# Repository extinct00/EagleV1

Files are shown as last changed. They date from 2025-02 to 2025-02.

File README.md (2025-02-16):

# EagleV1

## Low-cost split column-staggered ergonomic keyboard
A Corne-like split keyboard with a little bit wider thumb-cluster and more agressive pinky stagger. This keyboard is designed to be compatible with RedDragon LowProfile switches that are widely avaialable on AliExpress for very cheap. They have the same height as
Khail LP switches (around 12mm) and can be used with classic MX style keycaps, although some might hit the upper housing. Preffered are any keycaps compatible with Numphy keyboards or any 3D printed, either FDM or SLA.

---

## Table of Contents
1. [Introduction](#introduction)
2. [Features](#features)
3. [Bill of Materials](#bill-of-materials)
4. [Build Instructions](#build-instructions)
5. [Pictures](#pictures)
6. [Contributing](#contributing)
7. [License](#license)

---

## Introduction
This project is designed to create a split ergonomic keyboard that is both low-cost and low-profile. The keyboard is split into two halves, allowing for a more natural hand position and reducing strain during long typing sessions. The low-profile design ensures a sleek and modern look while maintaining comfort.

---

## Features
- **Split Design**: Ergonomically designed to reduce strain on your hands and wrists.
- **Low-Cost**: Built with affordable components to keep the project accessible.
- **Low-Profile**: Sleek and compact design for a modern look.
- **Customizable**: Open-source firmware and hardware for easy customization.

---

## Bill of Materials
Here’s a list of components you’ll need to build this keyboard. (You can fill this section with the specific parts you used.)

1. **Microcontroller**: (e.g., Pro Micro, RP2040, etc.)
2. **Key Switches**: (e.g., Low-profile mechanical switches)
3. **Keycaps**: (e.g., Low-profile keycaps)
4. **PCB or Handwiring Materials**: (e.g., PCB, diodes, wires)
5. **Case**: (e.g., 3D-printed or acrylic case)
6. **Connectors**: (e.g., TRRS cable for split communication)
7. **Miscellaneous**: (e.g., screws, standoffs, etc.)

---

## Build Instructions
Below is a step-by-step guide to building your split ergonomic keyboard. (You can fill in the details as you progress.)

### Step 1: Gather All Components
Ensure you have all the components listed in the [Bill of Materials](#bill-of-materials) section.

### Step 2: Prepare the PCB or Handwiring
- If using a PCB, solder the diodes and microcontroller.
- If handwiring, follow the wiring diagram and connect the switches to the microcontroller.

### Step 3: Assemble the Case
- Attach the switches to the case.
- Secure the PCB or handwired assembly into the case.

### Step 4: Connect the Two Halves
- Use a TRRS cable to connect the two halves of the keyboard.
- Ensure the firmware supports split communication.

### Step 5: Flash the Firmware
- Download and flash the firmware to the microcontroller.
- Customize the keymap if needed.

### Step 6: Test the Keyboard
- Connect the keyboard to your computer and test all keys.
- Make adjustments as necessary.

---

## Pictures
Here are some pictures of my progress and the final build. (You can add images from the `Pictures` folder as you go.)

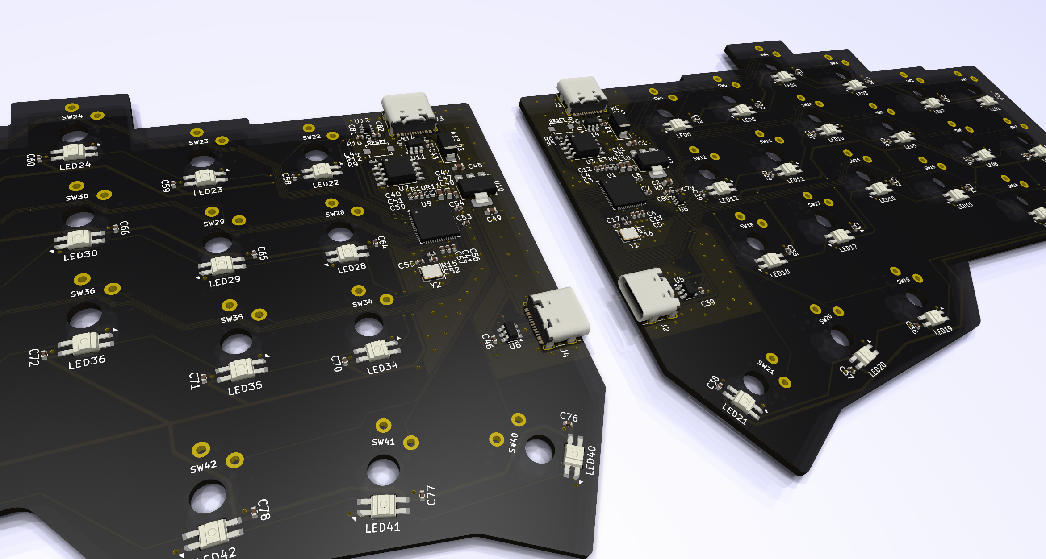
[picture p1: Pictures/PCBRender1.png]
Progress Photo 1

Progress Photo 2
Final Build

---

## Contributing
Contributions are welcome! If you have any suggestions, improvements, or bug fixes, feel free to open an issue or submit a pull request.

---

## License
This project is licensed under the [MIT License](LICENSE). Feel free to use, modify, and distribute it as you see fit.

---

Happy building! 🎛️

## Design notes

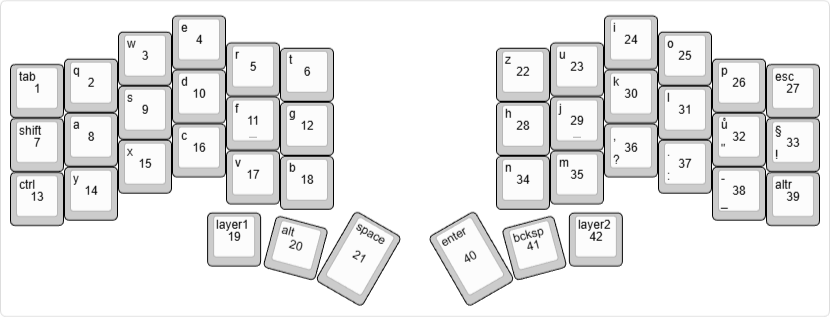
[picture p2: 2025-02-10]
Plate v3/project-eagle.png

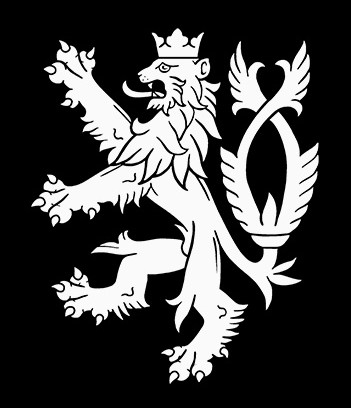
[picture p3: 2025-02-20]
PCB/EagleV1/_vyrn_1939plachta-lev.jpg

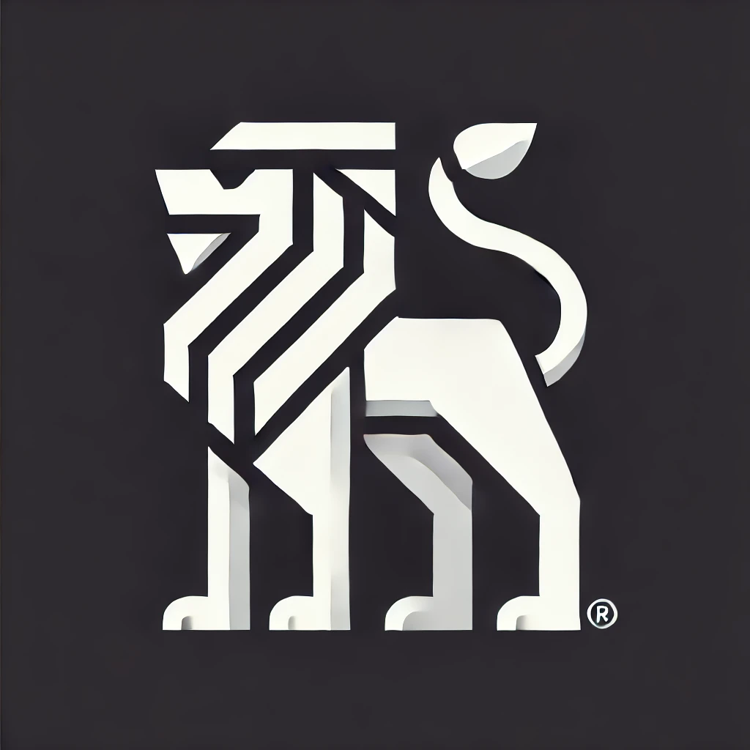
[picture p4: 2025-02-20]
PCB/EagleV1/cesky_lev_gpt.webp

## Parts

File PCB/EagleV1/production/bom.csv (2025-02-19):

Designator | Footprint | Quantity | Value | LCSC Part #
C1, C11, C2, C42, C45, C47, C49, C9 | 0603 | 8 | 1u
C10, C12, C13, C14, C15, C18, C19, C20, C21, C22, C23, C24, C25, C26, C27, C28, C29, C3, C30, C31, C32, C33, C34, C35, C36, C37, C38, C39, C4, C40, C41, C43, C44, C46, C48, C5, C50, C51, C53, C54, C56, C57, C58, C59, C6, C60, C61, C62, C63, C64, C65, C66, C67, C68, C69, C7, C70, C71, C72, C73, C74, C75, C76, C77, C78, C79, C8, C80, C81, C82 | 0402 | 70 | 100n
C16, C17, C52, C55 | 0402 | 4 | 15p
D1, D2 | D_SMA | 2 | SS14
J1, J2, J3, J4 | USB_C_Receptacle_G-Switch_GT-USB-7010ASV | 4 | USB_C_Receptacle_USB2.0_16P
LED1, LED10, LED11, LED12, LED13, LED14, LED15, LED16, LED17, LED18, LED19, LED2, LED20, LED21, LED22, LED23, LED24, LED25, LED26, LED27, LED28, LED29, LED3, LED30, LED31, LED32, LED33, LED34, LED35, LED36, LED37, LED38, LED39, LED4, LED40, LED41, LED42, LED5, LED6, LED7, LED8, LED9 | LED_6028R | 42 | SK6812MINI-E
MOUSBITES 0.5MM NPTH WITH 0.3MM SPACING_12, MOUSBITES 0.5MM NPTH WITH 0.3MM SPACING_11, MOUSBITES 0.5MM NPTH WITH 0.3MM SPACING_10, MOUSBITES 0.5MM NPTH WITH 0.3MM SPACING_9, MOUSBITES 0.5MM NPTH WITH 0.3MM SPACING_8, MOUSBITES 0.5MM NPTH WITH 0.3MM SPACING_7, MOUSBITES 0.5MM NPTH WITH 0.3MM SPACING_6, MOUSBITES 0.5MM NPTH WITH 0.3MM SPACING_5, MOUSBITES 0.5MM NPTH WITH 0.3MM SPACING_4, MOUSBITES 0.5MM NPTH WITH 0.3MM SPACING_3, MOUSBITES 0.5MM NPTH WITH 0.3MM SPACING_2, MOUSBITES 0.5MM NPTH WITH 0.3MM SPACING | Corne_mousebites | 12 | Corne_mousebites
R1, R13, R14, R2 | 0402 | 4 | 5.1k
R10, R11, R3, R4 | 0402 | 4 | 27
R12, R16, R5, R8 | 0402 | 4 | 10k
R15, R6, R7, R9 | 0402 | 4 | 1k
SW1, SW10, SW11, SW12, SW13, SW14, SW15, SW16, SW17, SW18, SW19, SW2, SW20, SW21, SW22, SW23, SW24, SW25, SW26, SW27, SW28, SW29, SW3, SW30, SW31, SW32, SW33, SW34, SW35, SW36, SW37, SW38, SW39, SW4, SW40, SW41, SW42, SW5, SW6, SW7, SW8, SW9 | SW_Redragon_LowProfile_PCB_1.00u | 42 | SW_Push
SW98, SW99 | SW_TS-1088_XNP | 2 | TS-1088-AR02016
U1, U9 | QFN-56-1EP_7x7mm_P0.4mm_EP3.2x3.2mm | 2 | RP2040
U10, U2 | SOT-223-3_TabPin2 | 2 | TLV1117-33
U11, U4, U5, U8 | SOT-23-6 | 4 | USBLC6-2SC6
U12, U6 | SOT-363_SC-70-6 | 2 | SN74LVC1T45DCK
U3, U7 | SOIC-8_5.23x5.23mm_P1.27mm | 2 | W25Q128JVS
Y1 | Crystal_SMD_3225-4Pin_3.2x2.5mm | 1 | Crystal_GND24
Y2 | Crystal_SMD_3225-4Pin_3.2x2.5mm | 1 | Crystal_GNDB24

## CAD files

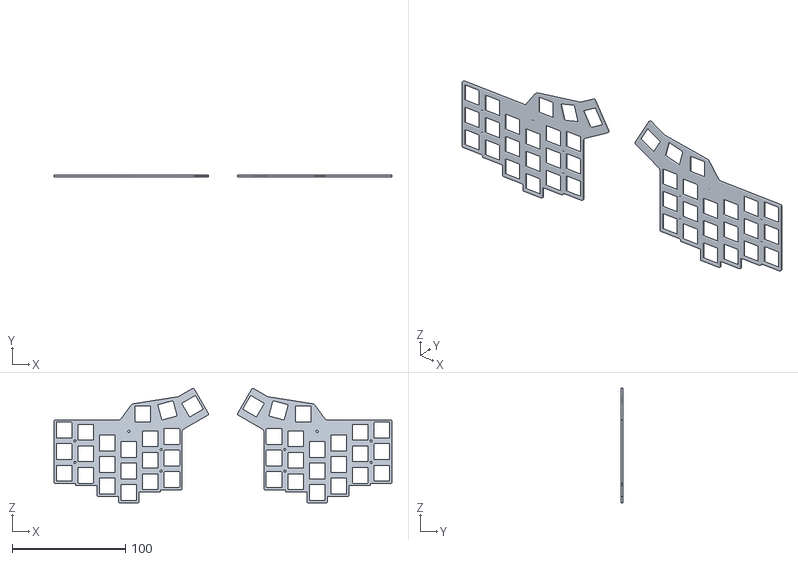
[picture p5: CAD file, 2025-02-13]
Plate v3/EagleV1 v12.stl
299.0 x 1.60 x 101.3

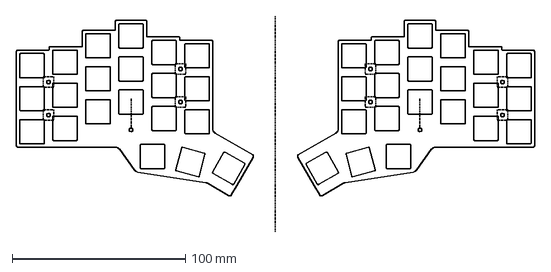
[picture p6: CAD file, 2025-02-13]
Plate v3/dxfSketchV3.dxf
299.0 x 124.5 mm

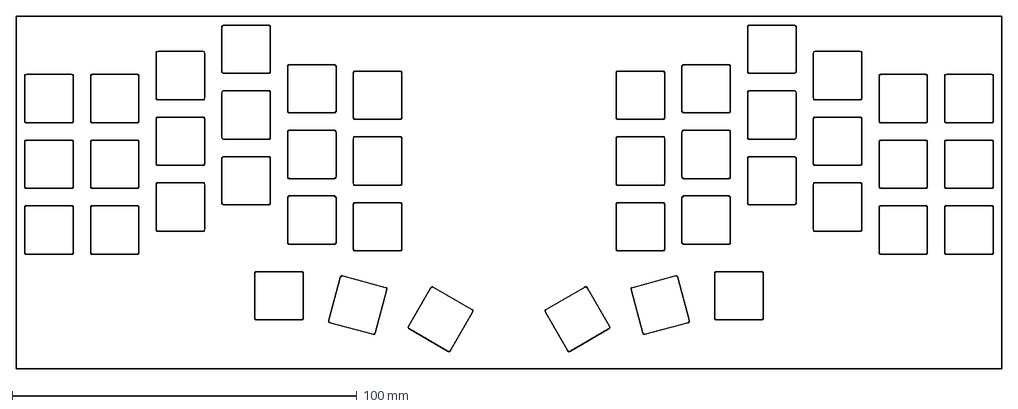
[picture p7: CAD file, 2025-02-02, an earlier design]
Plate v1/plate-2025-02-01T21_11_14.486Z.dxf
285.8 x 102.1 mm

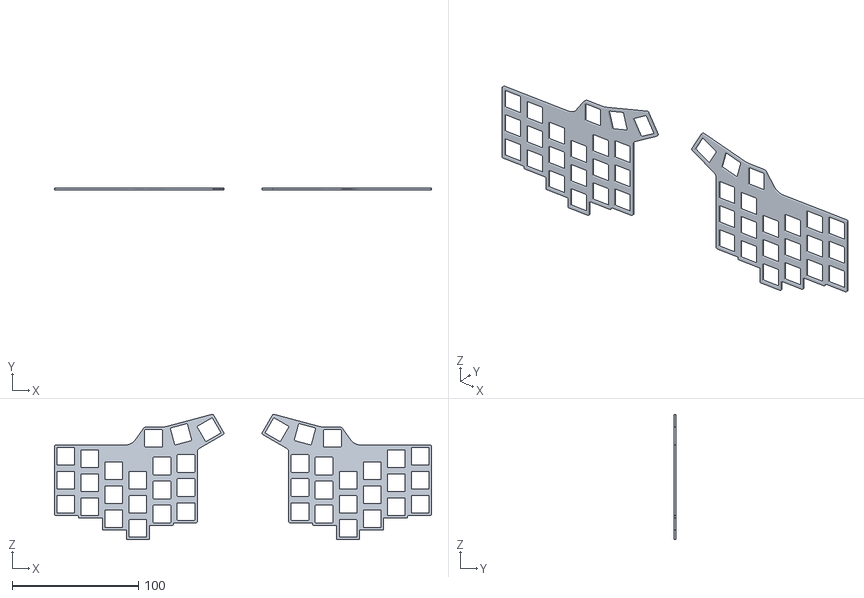
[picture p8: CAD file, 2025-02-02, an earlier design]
Plate v2/EagleV1_PlateV2.stl
299.0 x 1.60 x 99.5

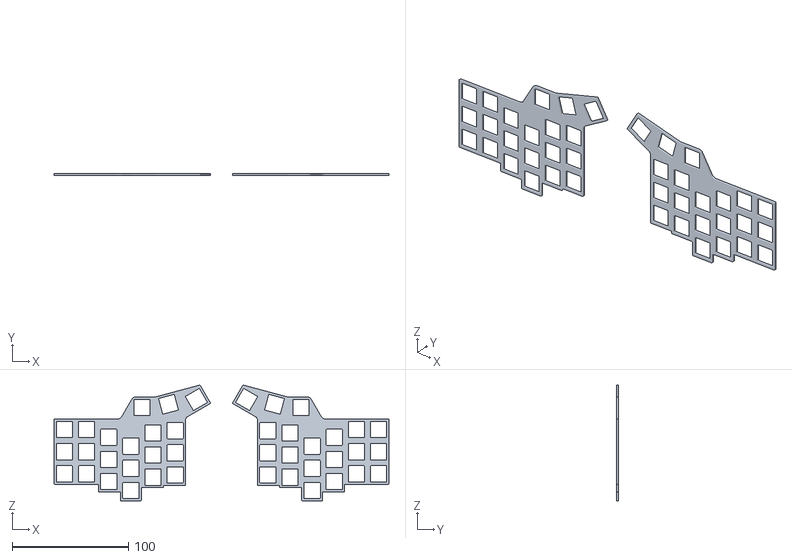
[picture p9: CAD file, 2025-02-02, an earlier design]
Plate v1/Eagle_v1_Plate v3.stl
288.2 x 1.60 x 99.7

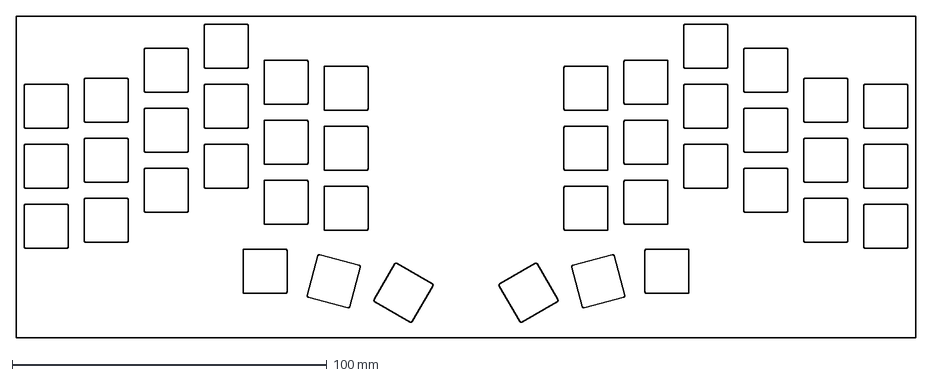
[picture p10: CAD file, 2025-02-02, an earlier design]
Plate v2/plate-2025-02-02T12_07_12.968Z.dxf
285.8 x 102.1 mm

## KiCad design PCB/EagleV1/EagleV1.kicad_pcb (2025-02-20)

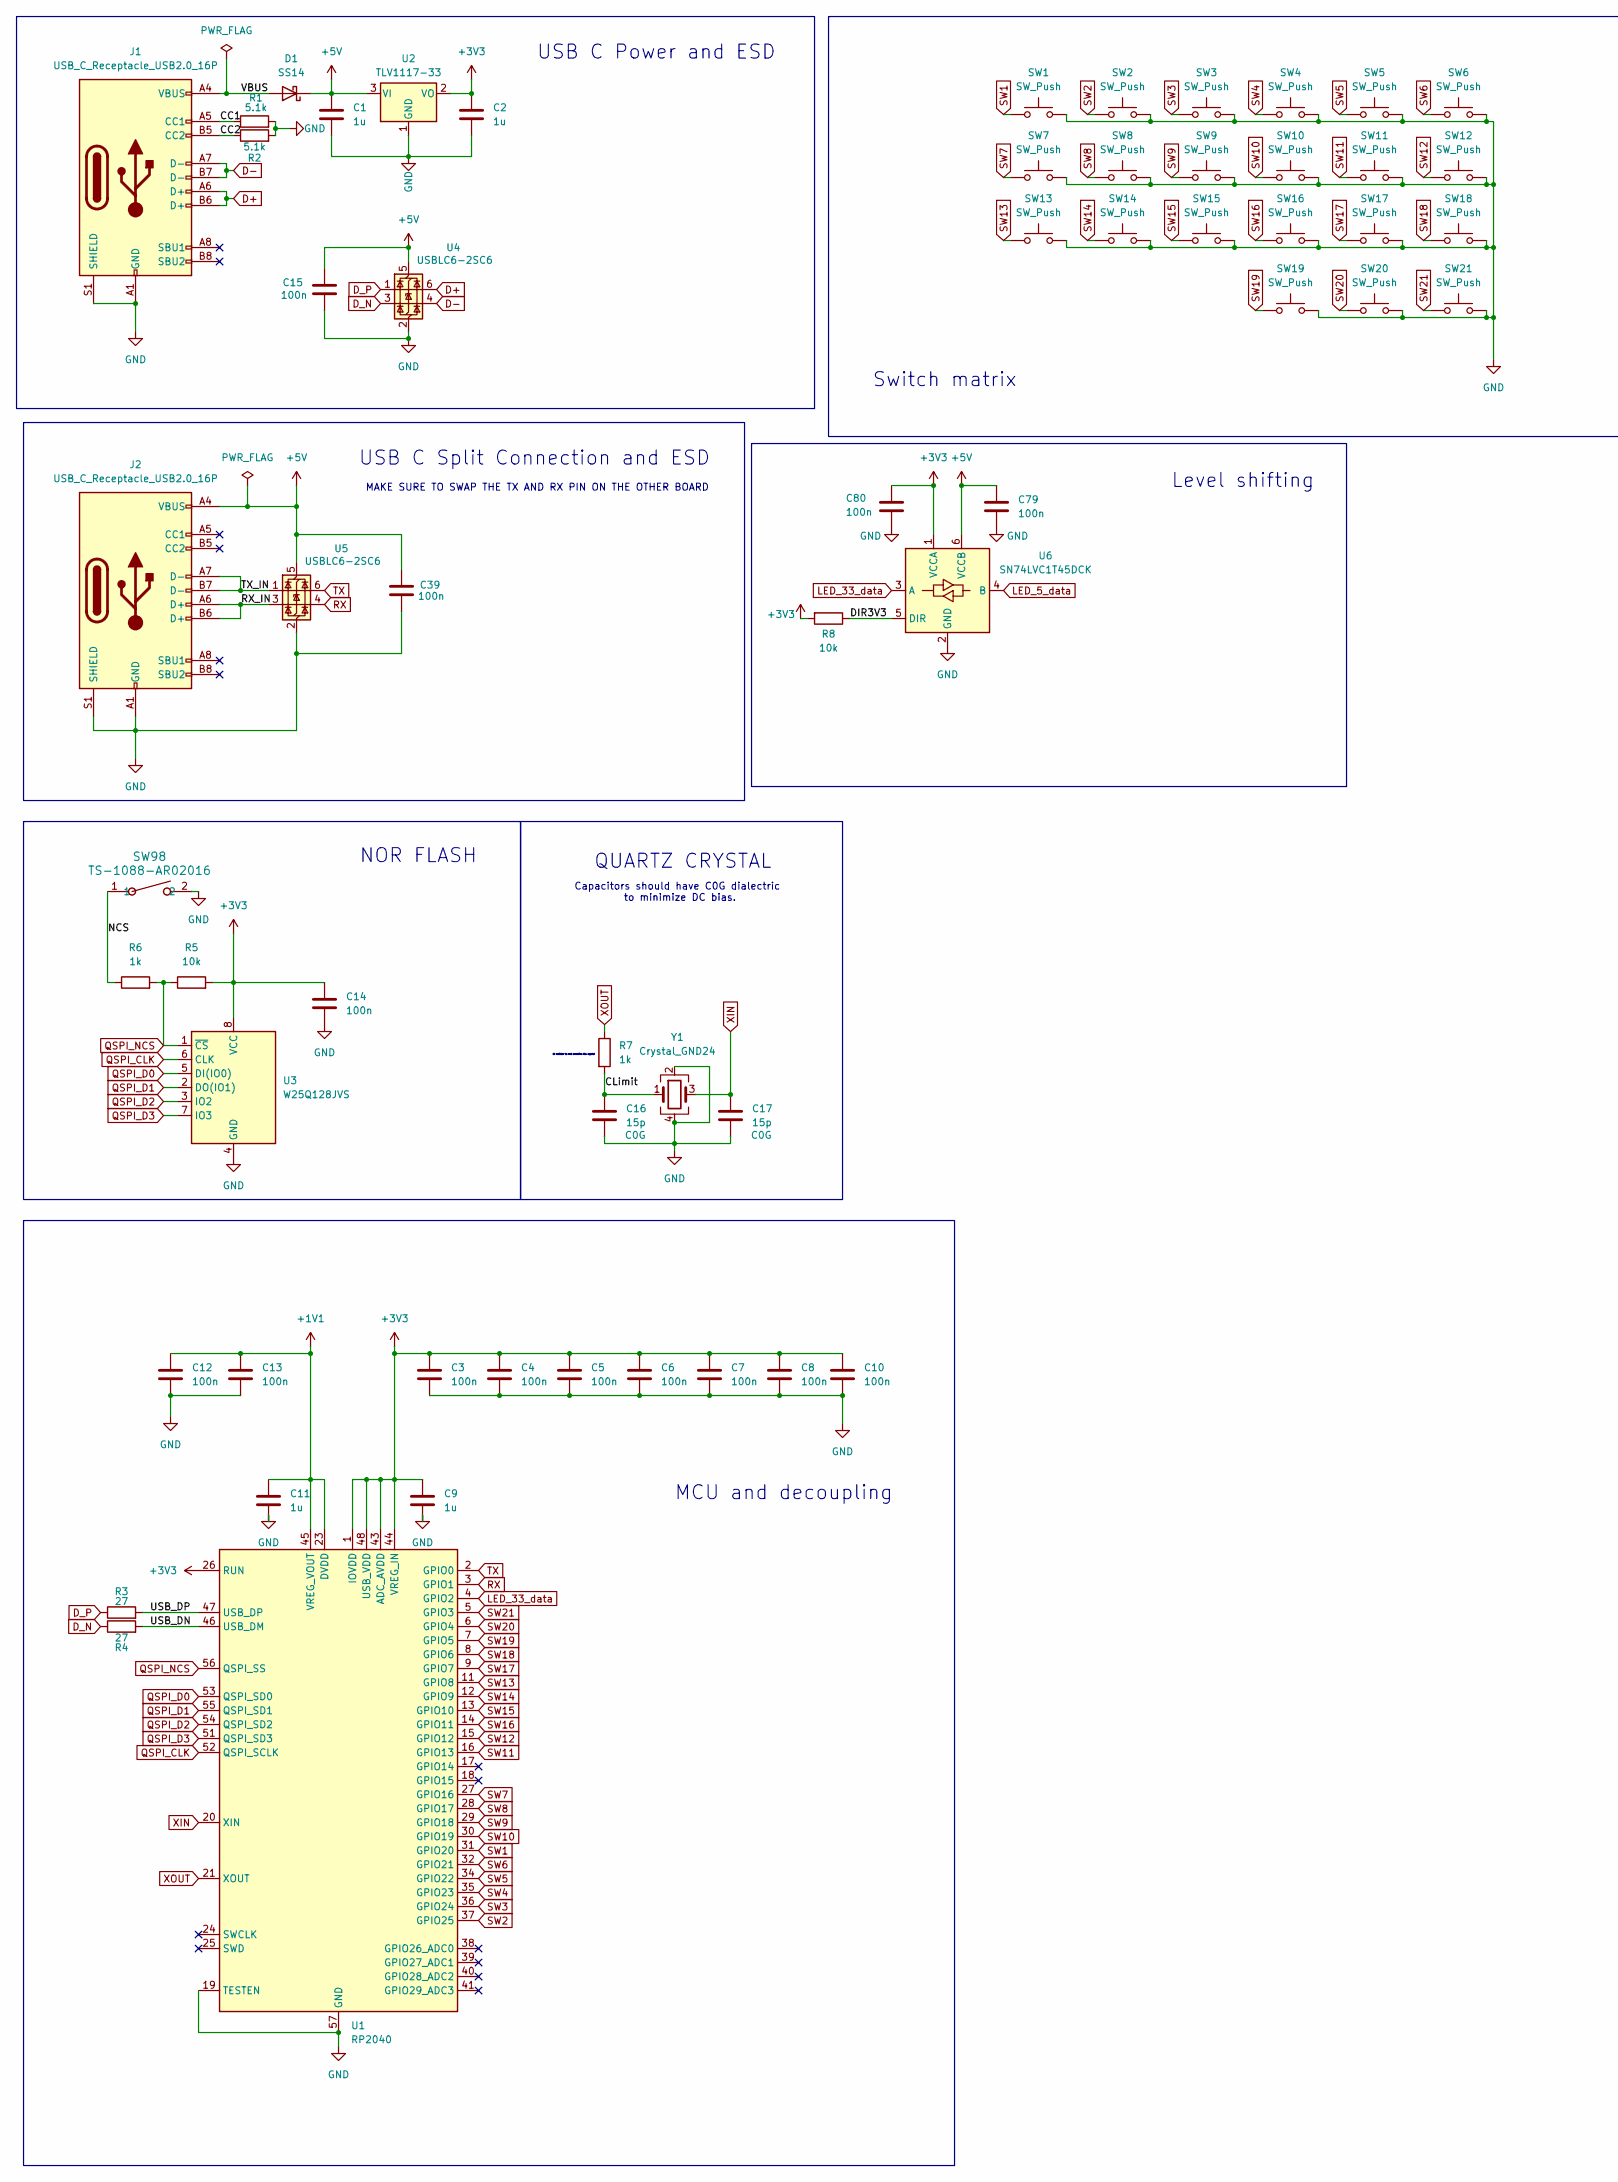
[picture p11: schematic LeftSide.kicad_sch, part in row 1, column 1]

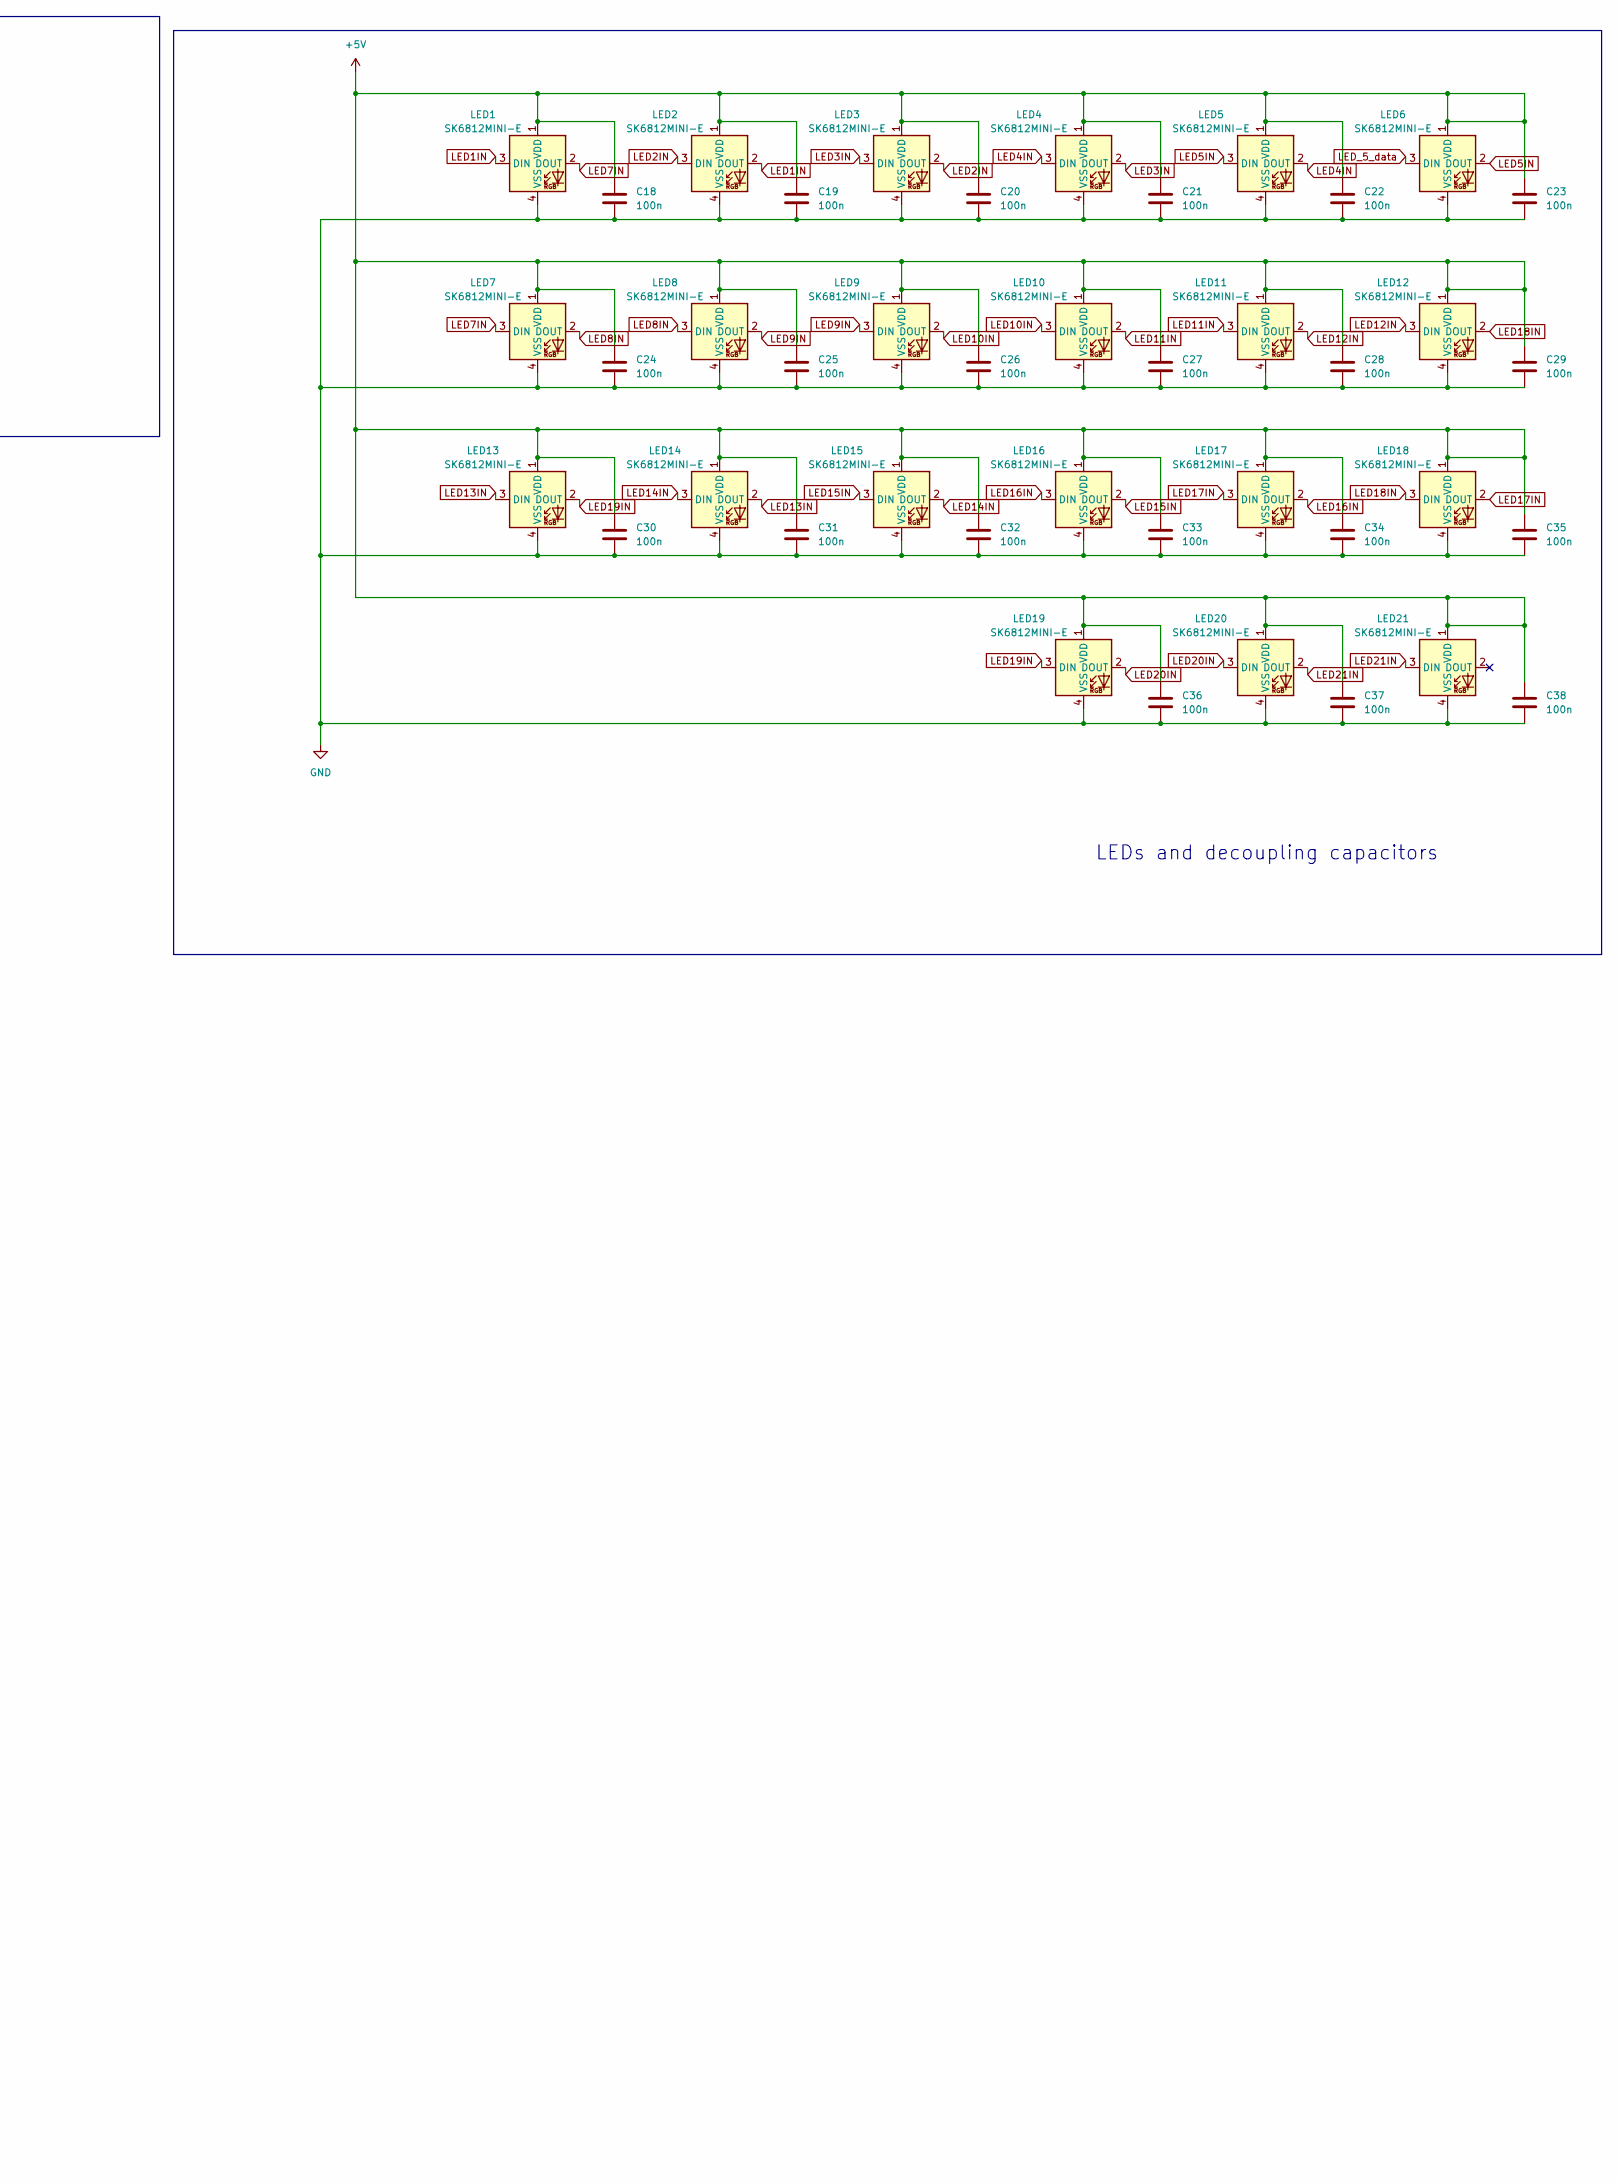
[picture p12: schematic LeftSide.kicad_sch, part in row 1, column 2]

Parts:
C1, C2, C9, C11: 1u; C_0603_1608Metric
C3, C4, C5, C6, C7, C8, C10, C12, C13, C14, C15, C18, C19, C20, C21, C22, C23, C24, C25, C26, C27, C28, C29, C30, C31, C32, C33, C34, C35, C36, C37, C38, C39, C79, C80: 100n; C_0402_1005Metric
C16, C17: 15p; C_0402_1005Metric
D1: SS14; D_SMA
J1, J2: USB_C_Receptacle_USB2.0_16P; USB_C_Receptacle_G-Switch_GT-USB-7010ASV
LED1, LED2, LED3, LED4, LED5, LED6, LED7, LED8, LED9, LED10, LED11, LED12, LED13, LED14, LED15, LED16, LED17, LED18, LED19, LED20, LED21: SK6812MINI-E; LED_6028R
R1, R2: 5.1k; R_0402_1005Metric
R3, R4: 27; R_0402_1005Metric
R5, R8: 10k; R_0402_1005Metric
R6, R7: 1k; R_0402_1005Metric
SW1, SW2, SW3, SW4, SW5, SW6, SW7, SW8, SW9, SW10, SW11, SW12, SW13, SW14, SW15, SW16, SW17, SW18, SW19, SW20, SW21: SW_Push; SW_Redragon_LowProfile_PCB_1.00u
SW98: TS-1088-AR02016; SW_TS-1088_XNP
U1: RP2040; QFN-56-1EP_7x7mm_P0.4mm_EP3.2x3.2mm
U2: TLV1117-33; SOT-223-3_TabPin2
U3: W25Q128JVS; SOIC-8_5.23x5.23mm_P1.27mm
U4, U5: USBLC6-2SC6; SOT-23-6
U6: SN74LVC1T45DCK; SOT-363_SC-70-6
Y1: Crystal_GND24; Crystal_SMD_3225-4Pin_3.2x2.5mm

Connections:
+1V1: C11.1, C12.1, C13.1, U1.23 (DVDD), U1.45 (VREG_VOUT), U1.50 (DVDD)
+3V3: C2.1, C3.1, C4.1, C5.1, C6.1, C7.1, C8.1, C9.1, C10.1, C14.1, C80.1, R5.2, R8.2, U1.1 (IOVDD), U1.10 (IOVDD), U1.22 (IOVDD), U1.26 (RUN), U1.33 (IOVDD), U1.42 (IOVDD), U1.43 (ADC_AVDD), U1.44 (VREG_IN), U1.48 (USB_VDD), U1.49 (IOVDD), U2.2 (VO), U3.8 (VCC), U6.1 (VCCA)
+5V: C1.1, C15.2, C18.2, C19.2, C20.2, C21.2, C22.2, C23.2, C24.2, C25.2, C26.2, C27.2, C28.2, C29.2, C30.2, C31.2, C32.2, C33.2, C34.2, C35.2, C36.2, C37.2, C38.2, C39.2, C79.1, D1.1 (K), J2.A4 (VBUS), J2.A9 (VBUS), J2.B4 (VBUS), J2.B9 (VBUS), LED1.1 (VDD), LED2.1 (VDD), LED3.1 (VDD), LED4.1 (VDD), LED5.1 (VDD), LED6.1 (VDD), LED7.1 (VDD), LED8.1 (VDD), LED9.1 (VDD), LED10.1 (VDD), LED11.1 (VDD), LED12.1 (VDD), LED13.1 (VDD), LED14.1 (VDD), LED15.1 (VDD), LED16.1 (VDD), LED17.1 (VDD), LED18.1 (VDD), LED19.1 (VDD), LED20.1 (VDD), LED21.1 (VDD), U2.3 (VI), U4.5 (VBUS), U5.5 (VBUS), U6.6 (VCCB)
/LeftSide/CC1: J1.A5 (CC1), R1.1
/LeftSide/CC2: J1.B5 (CC2), R2.1
/LeftSide/CLimit: C16.1, R7.2, Y1.1
/LeftSide/DIR3V3: R8.1, U6.5 (DIR)
/LeftSide/NCS: R6.1, SW98.1
/LeftSide/RX_IN: J2.A6 (D+), J2.B6 (D+), U5.3 (I/O2)
/LeftSide/TX_IN: J2.A7 (D-), J2.B7 (D-), U5.1 (I/O1)
/LeftSide/USB_DN: R4.2, U1.46 (USB_DM)
/LeftSide/USB_DP: R3.2, U1.47 (USB_DP)
/LeftSide/VBUS: D1.2 (A), J1.A4 (VBUS), J1.A9 (VBUS), J1.B4 (VBUS), J1.B9 (VBUS)
D+: J1.A6 (D+), J1.B6 (D+), U4.6 (I/O1)
D-: J1.A7 (D-), J1.B7 (D-), U4.4 (I/O2)
D_N: R4.1, U4.3 (I/O2)
D_P: R3.1, U4.1 (I/O1)
GND: C1.2, C2.2, C3.2, C4.2, C5.2, C6.2, C7.2, C8.2, C9.2, C10.2, C11.2, C12.2, C13.2, C14.2, C15.1, C16.2, C17.2, C18.1, C19.1, C20.1, C21.1, C22.1, C23.1, C24.1, C25.1, C26.1, C27.1, C28.1, C29.1, C30.1, C31.1, C32.1, C33.1, C34.1, C35.1, C36.1, C37.1, C38.1, C39.1, C79.2, C80.2, J1.A1 (GND), J1.A12 (GND), J1.B1 (GND), J1.B12 (GND), J1.S1 (SHIELD), J2.A1 (GND), J2.A12 (GND), J2.B1 (GND), J2.B12 (GND), J2.S1 (SHIELD), LED1.4 (VSS), LED2.4 (VSS), LED3.4 (VSS), LED4.4 (VSS), LED5.4 (VSS), LED6.4 (VSS), LED7.4 (VSS), LED8.4 (VSS), LED9.4 (VSS), LED10.4 (VSS), LED11.4 (VSS), LED12.4 (VSS), LED13.4 (VSS), LED14.4 (VSS), LED15.4 (VSS), LED16.4 (VSS), LED17.4 (VSS), LED18.4 (VSS), LED19.4 (VSS), LED20.4 (VSS), LED21.4 (VSS), R1.2, R2.2, SW1.2, SW2.2, SW3.2, SW4.2, SW5.2, SW6.2, SW7.2, SW8.2, SW9.2, SW10.2, SW11.2, SW12.2, SW13.2, SW14.2, SW15.2, SW16.2, SW17.2, SW18.2, SW19.2, SW20.2, SW21.2, SW98.2, U1.19 (TESTEN), U1.57 (GND), U2.1 (GND), U3.4 (GND), U4.2 (GND), U5.2 (GND), U6.2 (GND), Y1.2, Y1.4
LED1IN: LED1.3 (DIN), LED2.2 (DOUT)
LED2IN: LED2.3 (DIN), LED3.2 (DOUT)
LED3IN: LED3.3 (DIN), LED4.2 (DOUT)
LED4IN: LED4.3 (DIN), LED5.2 (DOUT)
LED5IN: LED5.3 (DIN), LED6.2 (DOUT)
LED7IN: LED1.2 (DOUT), LED7.3 (DIN)
LED8IN: LED7.2 (DOUT), LED8.3 (DIN)
LED9IN: LED8.2 (DOUT), LED9.3 (DIN)
LED10IN: LED9.2 (DOUT), LED10.3 (DIN)
LED11IN: LED10.2 (DOUT), LED11.3 (DIN)
LED12IN: LED11.2 (DOUT), LED12.3 (DIN)
LED13IN: LED13.3 (DIN), LED14.2 (DOUT)
LED14IN: LED14.3 (DIN), LED15.2 (DOUT)
LED15IN: LED15.3 (DIN), LED16.2 (DOUT)
LED16IN: LED16.3 (DIN), LED17.2 (DOUT)
LED17IN: LED17.3 (DIN), LED18.2 (DOUT)
LED18IN: LED12.2 (DOUT), LED18.3 (DIN)
LED19IN: LED13.2 (DOUT), LED19.3 (DIN)
LED20IN: LED19.2 (DOUT), LED20.3 (DIN)
LED21IN: LED20.2 (DOUT), LED21.3 (DIN)
LED_5_data: LED6.3 (DIN), U6.4 (B)
LED_33_data: U1.4 (GPIO2), U6.3 (A)
QSPI_CLK: U1.52 (QSPI_SCLK), U3.6 (CLK)
QSPI_D0: U1.53 (QSPI_SD0), U3.5 (DI(IO0))
QSPI_D1: U1.55 (QSPI_SD1), U3.2 (DO(IO1))
QSPI_D2: U1.54 (QSPI_SD2), U3.3 (IO2)
QSPI_D3: U1.51 (QSPI_SD3), U3.7 (IO3)
QSPI_NCS: R5.1, R6.2, U1.56 (QSPI_SS), U3.1 (~CS)
RX: U1.3 (GPIO1), U5.4 (I/O2)
SW1: SW1.1, U1.31 (GPIO20)
SW2: SW2.1, U1.37 (GPIO25)
SW3: SW3.1, U1.36 (GPIO24)
SW4: SW4.1, U1.35 (GPIO23)
SW5: SW5.1, U1.34 (GPIO22)
SW6: SW6.1, U1.32 (GPIO21)
SW7: SW7.1, U1.27 (GPIO16)
SW8: SW8.1, U1.28 (GPIO17)
SW9: SW9.1, U1.29 (GPIO18)
SW10: SW10.1, U1.30 (GPIO19)
SW11: SW11.1, U1.16 (GPIO13)
SW12: SW12.1, U1.15 (GPIO12)
SW13: SW13.1, U1.11 (GPIO8)
SW14: SW14.1, U1.12 (GPIO9)
SW15: SW15.1, U1.13 (GPIO10)
SW16: SW16.1, U1.14 (GPIO11)
SW17: SW17.1, U1.9 (GPIO7)
SW18: SW18.1, U1.8 (GPIO6)
SW19: SW19.1, U1.7 (GPIO5)
SW20: SW20.1, U1.6 (GPIO4)
SW21: SW21.1, U1.5 (GPIO3)
TX: U1.2 (GPIO0), U5.6 (I/O1)
XIN: C17.1, U1.20 (XIN), Y1.3
XOUT: R7.1, U1.21 (XOUT)

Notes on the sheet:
Capacitors should have C0G dialectric to minimize DC bias.
NOR FLASH
MAKE SURE TO SWAP THE TX AND RX PIN ON THE OTHER BOARD
USB C Power and ESD
LEDs and decoupling capacitors
1k resistor to not overdrive the crystal
USB C Split Connection and ESD
Level shifting
MCU and decoupling
QUARTZ CRYSTAL
Switch matrix

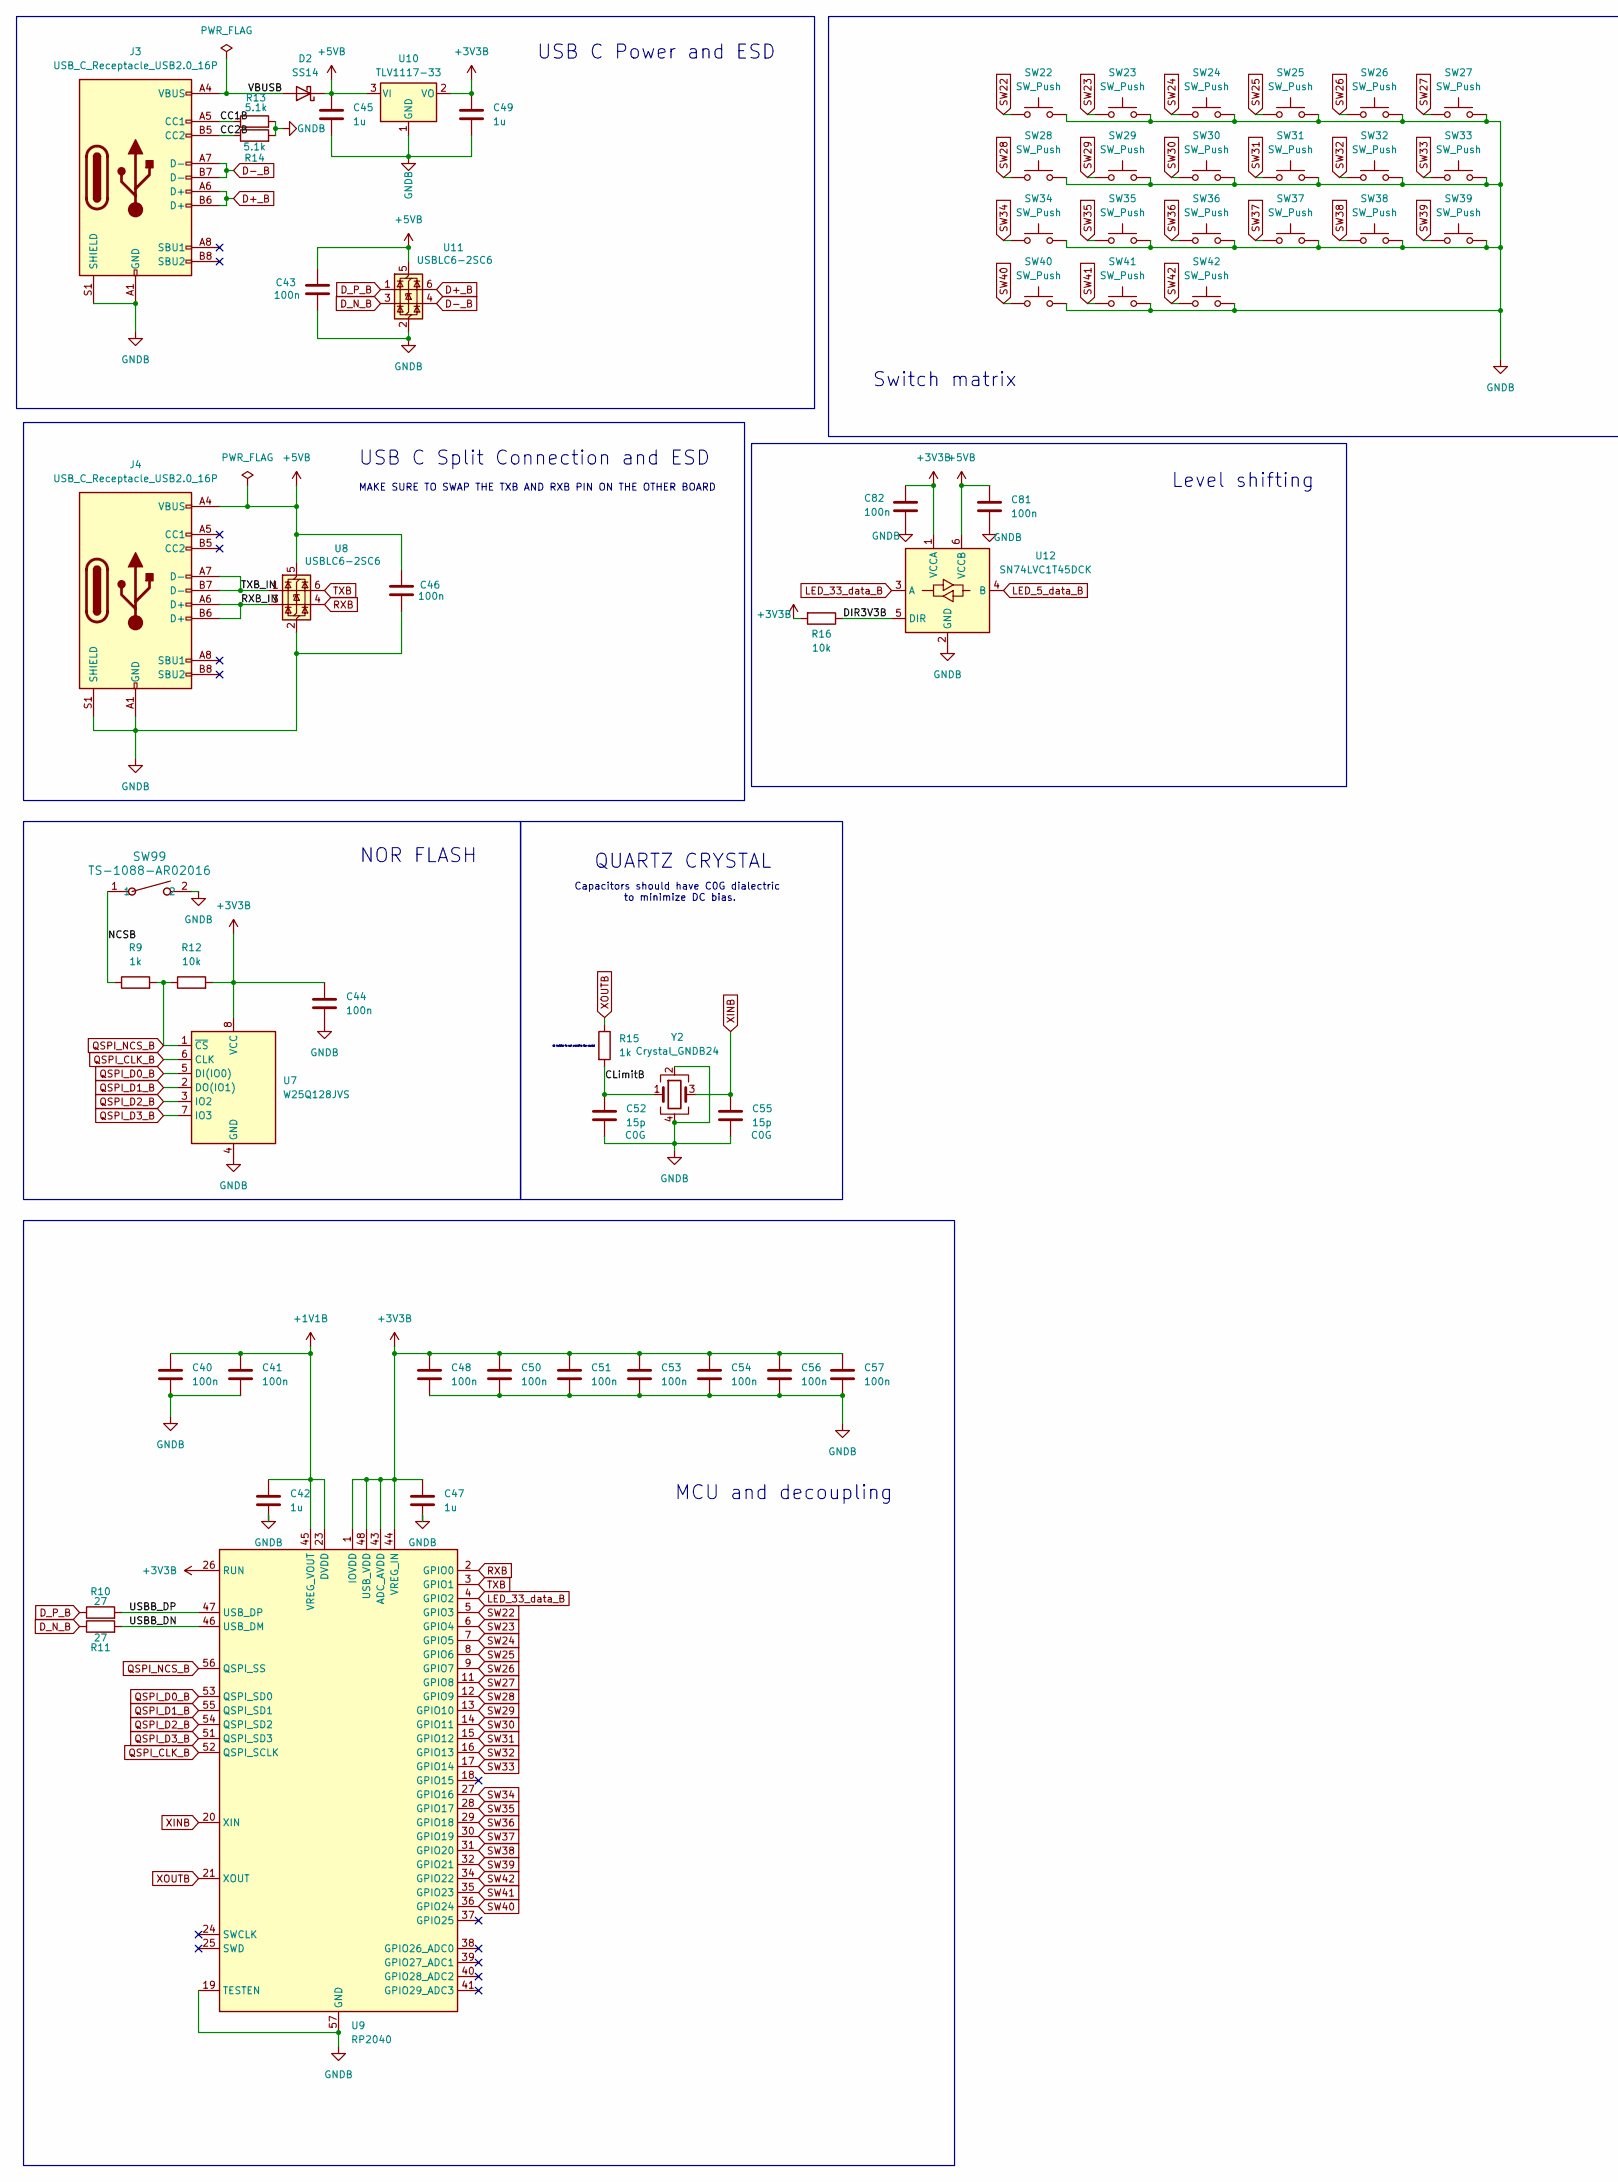
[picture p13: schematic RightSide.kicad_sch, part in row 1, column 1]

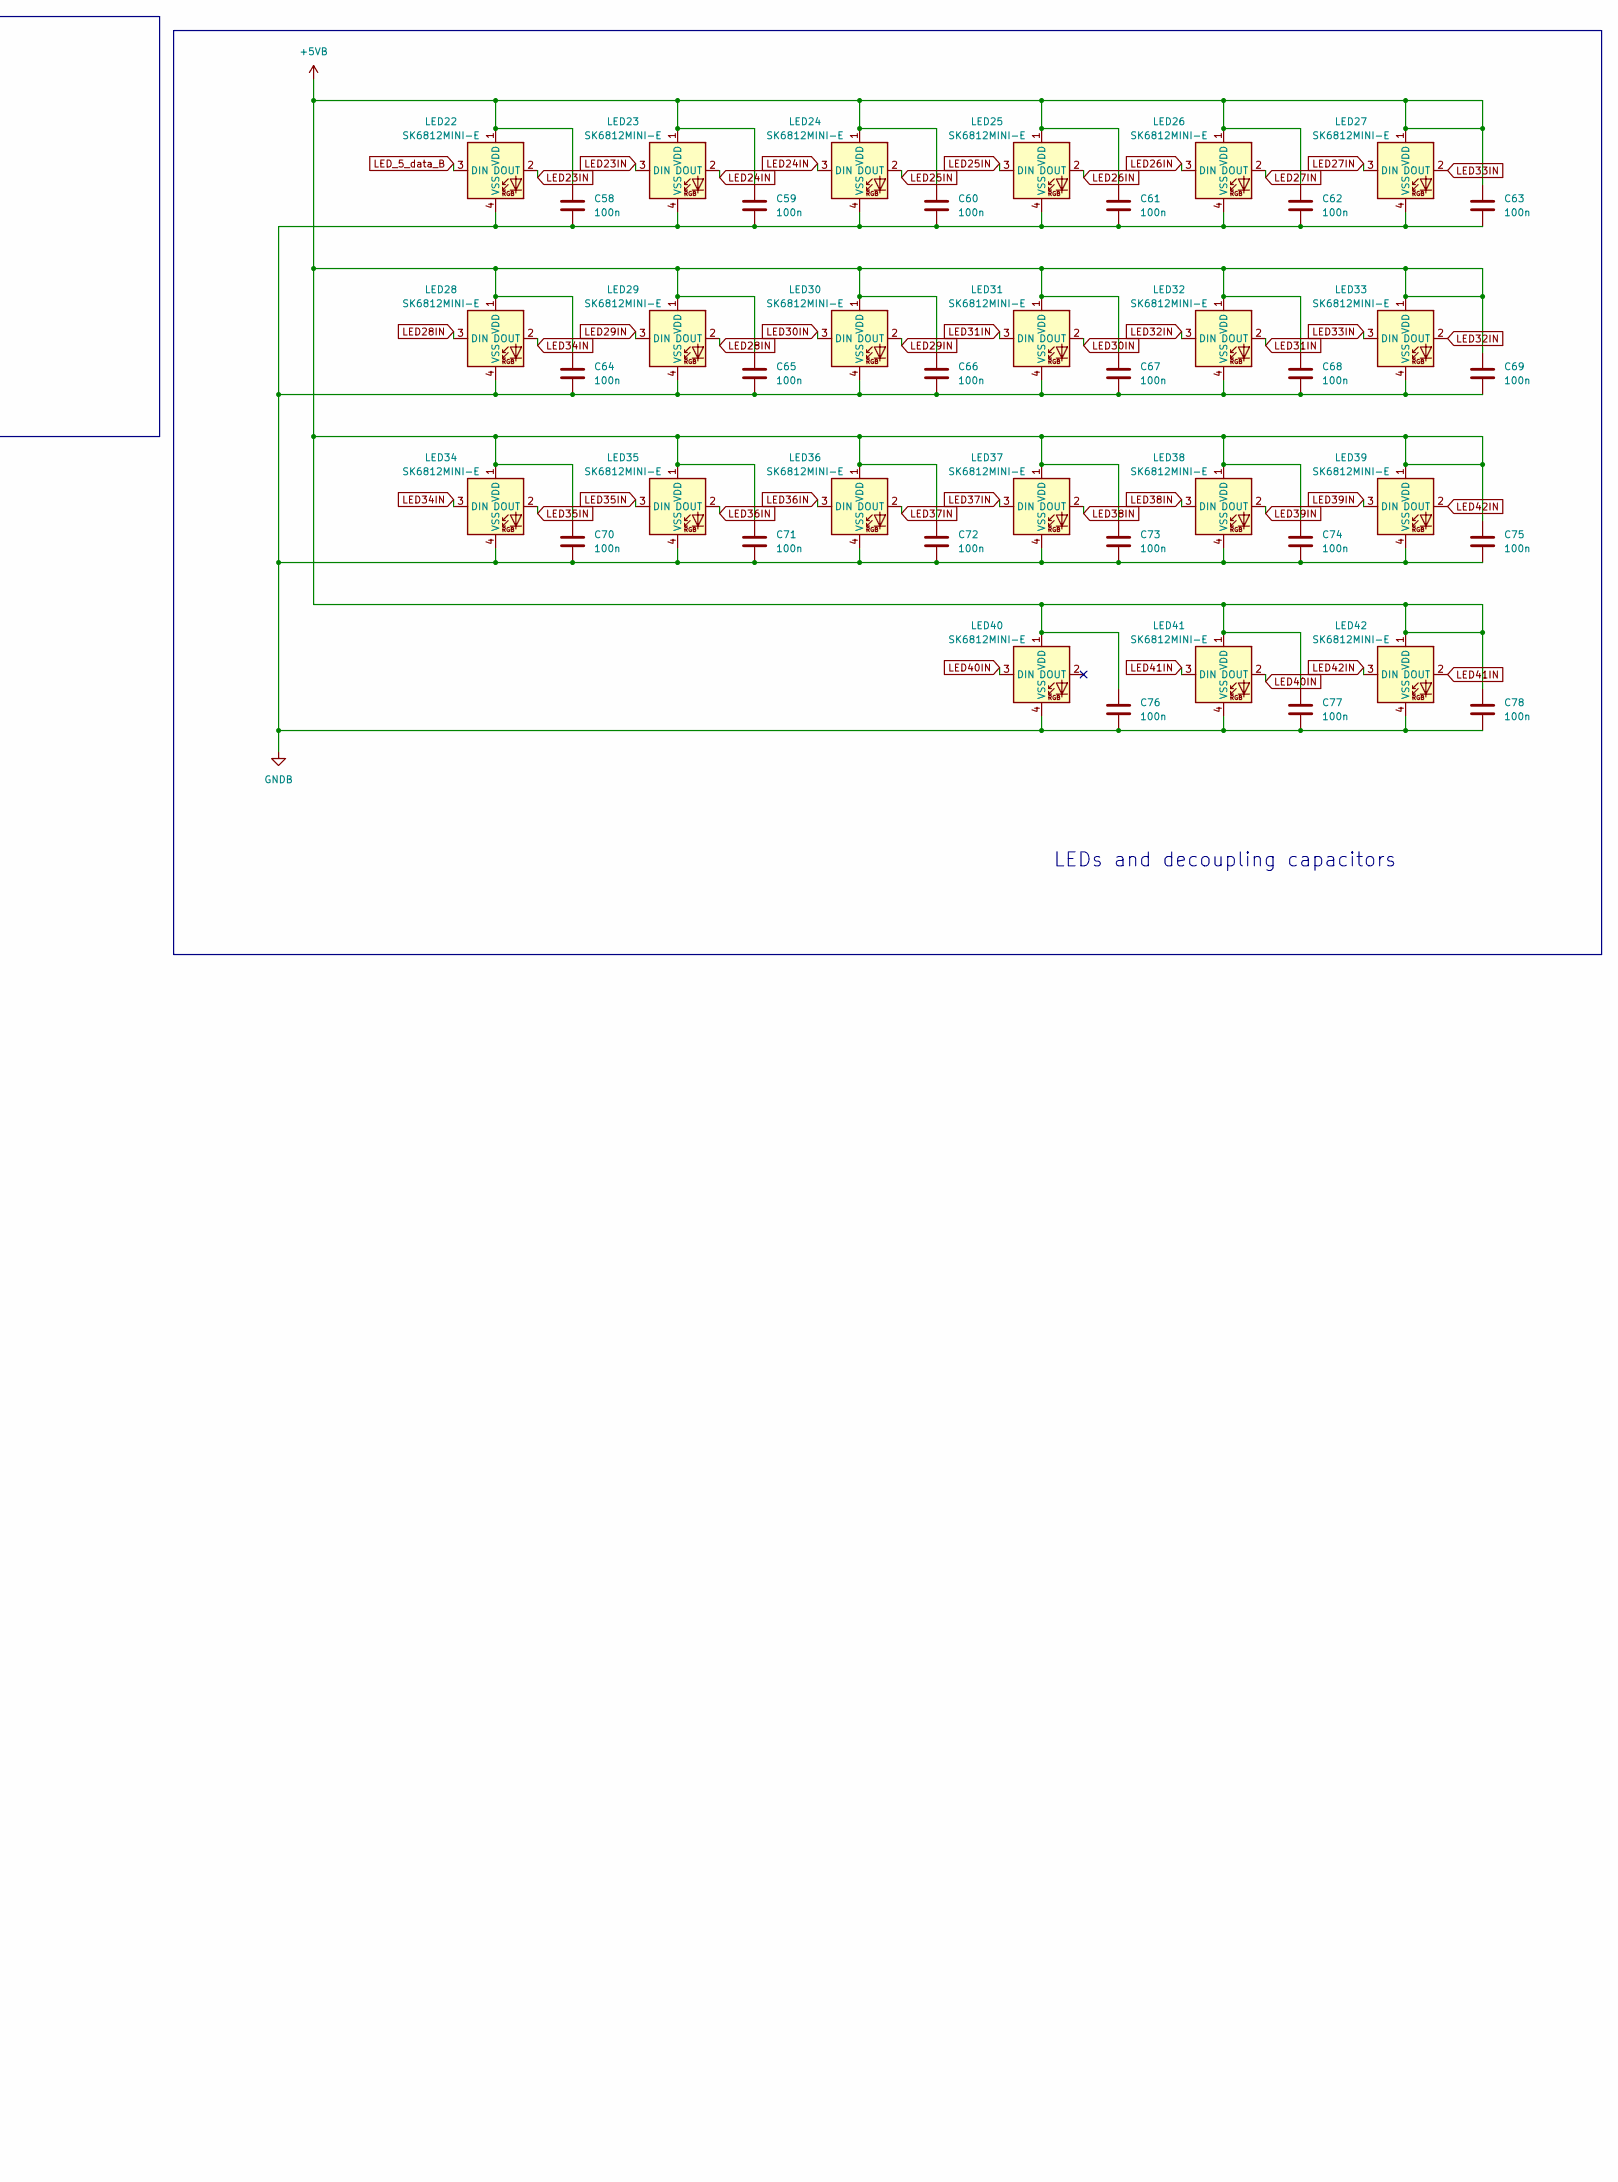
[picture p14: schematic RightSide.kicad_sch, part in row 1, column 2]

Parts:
C40, C41, C43, C44, C46, C48, C50, C51, C53, C54, C56, C57, C58, C59, C60, C61, C62, C63, C64, C65, C66, C67, C68, C69, C70, C71, C72, C73, C74, C75, C76, C77, C78, C81, C82: 100n; C_0402_1005Metric
C42, C45, C47, C49: 1u; C_0603_1608Metric
C52, C55: 15p; C_0402_1005Metric
D2: SS14; D_SMA
J3, J4: USB_C_Receptacle_USB2.0_16P; USB_C_Receptacle_G-Switch_GT-USB-7010ASV
LED22, LED23, LED24, LED25, LED26, LED27, LED28, LED29, LED30, LED31, LED32, LED33, LED34, LED35, LED36, LED37, LED38, LED39, LED40, LED41, LED42: SK6812MINI-E; LED_6028R
R9, R15: 1k; R_0402_1005Metric
R10, R11: 27; R_0402_1005Metric
R12, R16: 10k; R_0402_1005Metric
R13, R14: 5.1k; R_0402_1005Metric
SW22, SW23, SW24, SW25, SW26, SW27, SW28, SW29, SW30, SW31, SW32, SW33, SW34, SW35, SW36, SW37, SW38, SW39, SW40, SW41, SW42: SW_Push; SW_Redragon_LowProfile_PCB_1.00u
SW99: TS-1088-AR02016; SW_TS-1088_XNP
U7: W25Q128JVS; SOIC-8_5.23x5.23mm_P1.27mm
U8, U11: USBLC6-2SC6; SOT-23-6
U9: RP2040; QFN-56-1EP_7x7mm_P0.4mm_EP3.2x3.2mm
U10: TLV1117-33; SOT-223-3_TabPin2
U12: SN74LVC1T45DCK; SOT-363_SC-70-6
Y2: Crystal_GNDB24; Crystal_SMD_3225-4Pin_3.2x2.5mm

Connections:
+1V1B: C40.1, C41.1, C42.1, U9.23 (DVDD), U9.45 (VREG_VOUT), U9.50 (DVDD)
+3V3B: C44.1, C47.1, C48.1, C49.1, C50.1, C51.1, C53.1, C54.1, C56.1, C57.1, C82.1, R12.2, R16.2, U7.8 (VCC), U9.1 (IOVDD), U9.10 (IOVDD), U9.22 (IOVDD), U9.26 (RUN), U9.33 (IOVDD), U9.42 (IOVDD), U9.43 (ADC_AVDD), U9.44 (VREG_IN), U9.48 (USB_VDD), U9.49 (IOVDD), U10.2 (VO), U12.1 (VCCA)
+5VB: C43.2, C45.1, C46.2, C58.2, C59.2, C60.2, C61.2, C62.2, C63.2, C64.2, C65.2, C66.2, C67.2, C68.2, C69.2, C70.2, C71.2, C72.2, C73.2, C74.2, C75.2, C76.2, C77.2, C78.2, C81.1, D2.1 (K), J4.A4 (VBUS), J4.A9 (VBUS), J4.B4 (VBUS), J4.B9 (VBUS), LED22.1 (VDD), LED23.1 (VDD), LED24.1 (VDD), LED25.1 (VDD), LED26.1 (VDD), LED27.1 (VDD), LED28.1 (VDD), LED29.1 (VDD), LED30.1 (VDD), LED31.1 (VDD), LED32.1 (VDD), LED33.1 (VDD), LED34.1 (VDD), LED35.1 (VDD), LED36.1 (VDD), LED37.1 (VDD), LED38.1 (VDD), LED39.1 (VDD), LED40.1 (VDD), LED41.1 (VDD), LED42.1 (VDD), U8.5 (VBUS), U10.3 (VI), U11.5 (VBUS), U12.6 (VCCB)
/RightSide/CC1B: J3.A5 (CC1), R13.1
/RightSide/CC2B: J3.B5 (CC2), R14.1
/RightSide/CLimitB: C52.1, R15.2, Y2.1
/RightSide/DIR3V3B: R16.1, U12.5 (DIR)
/RightSide/NCSB: R9.1, SW99.1
/RightSide/RXB_IN: J4.A6 (D+), J4.B6 (D+), U8.3 (I/O2)
/RightSide/TXB_IN: J4.A7 (D-), J4.B7 (D-), U8.1 (I/O1)
/RightSide/USBB_DN: R11.2, U9.46 (USB_DM)
/RightSide/USBB_DP: R10.2, U9.47 (USB_DP)
/RightSide/VBUSB: D2.2 (A), J3.A4 (VBUS), J3.A9 (VBUS), J3.B4 (VBUS), J3.B9 (VBUS)
D+_B: J3.A6 (D+), J3.B6 (D+), U11.6 (I/O1)
D-_B: J3.A7 (D-), J3.B7 (D-), U11.4 (I/O2)
D_N_B: R11.1, U11.3 (I/O2)
D_P_B: R10.1, U11.1 (I/O1)
GNDB: C40.2, C41.2, C42.2, C43.1, C44.2, C45.2, C46.1, C47.2, C48.2, C49.2, C50.2, C51.2, C52.2, C53.2, C54.2, C55.2, C56.2, C57.2, C58.1, C59.1, C60.1, C61.1, C62.1, C63.1, C64.1, C65.1, C66.1, C67.1, C68.1, C69.1, C70.1, C71.1, C72.1, C73.1, C74.1, C75.1, C76.1, C77.1, C78.1, C81.2, C82.2, J3.A1 (GND), J3.A12 (GND), J3.B1 (GND), J3.B12 (GND), J3.S1 (SHIELD), J4.A1 (GND), J4.A12 (GND), J4.B1 (GND), J4.B12 (GND), J4.S1 (SHIELD), LED22.4 (VSS), LED23.4 (VSS), LED24.4 (VSS), LED25.4 (VSS), LED26.4 (VSS), LED27.4 (VSS), LED28.4 (VSS), LED29.4 (VSS), LED30.4 (VSS), LED31.4 (VSS), LED32.4 (VSS), LED33.4 (VSS), LED34.4 (VSS), LED35.4 (VSS), LED36.4 (VSS), LED37.4 (VSS), LED38.4 (VSS), LED39.4 (VSS), LED40.4 (VSS), LED41.4 (VSS), LED42.4 (VSS), R13.2, R14.2, SW22.2, SW23.2, SW24.2, SW25.2, SW26.2, SW27.2, SW28.2, SW29.2, SW30.2, SW31.2, SW32.2, SW33.2, SW34.2, SW35.2, SW36.2, SW37.2, SW38.2, SW39.2, SW40.2, SW41.2, SW42.2, SW99.2, U7.4 (GND), U8.2 (GND), U9.19 (TESTEN), U9.57 (GND), U10.1 (GND), U11.2 (GND), U12.2 (GND), Y2.2, Y2.4
LED23IN: LED22.2 (DOUT), LED23.3 (DIN)
LED24IN: LED23.2 (DOUT), LED24.3 (DIN)
LED25IN: LED24.2 (DOUT), LED25.3 (DIN)
LED26IN: LED25.2 (DOUT), LED26.3 (DIN)
LED27IN: LED26.2 (DOUT), LED27.3 (DIN)
LED28IN: LED28.3 (DIN), LED29.2 (DOUT)
LED29IN: LED29.3 (DIN), LED30.2 (DOUT)
LED30IN: LED30.3 (DIN), LED31.2 (DOUT)
LED31IN: LED31.3 (DIN), LED32.2 (DOUT)
LED32IN: LED32.3 (DIN), LED33.2 (DOUT)
LED33IN: LED27.2 (DOUT), LED33.3 (DIN)
LED34IN: LED28.2 (DOUT), LED34.3 (DIN)
LED35IN: LED34.2 (DOUT), LED35.3 (DIN)
LED36IN: LED35.2 (DOUT), LED36.3 (DIN)
LED37IN: LED36.2 (DOUT), LED37.3 (DIN)
LED38IN: LED37.2 (DOUT), LED38.3 (DIN)
LED39IN: LED38.2 (DOUT), LED39.3 (DIN)
LED40IN: LED40.3 (DIN), LED41.2 (DOUT)
LED41IN: LED41.3 (DIN), LED42.2 (DOUT)
LED42IN: LED39.2 (DOUT), LED42.3 (DIN)
LED_5_data_B: LED22.3 (DIN), U12.4 (B)
LED_33_data_B: U9.4 (GPIO2), U12.3 (A)
QSPI_CLK_B: U7.6 (CLK), U9.52 (QSPI_SCLK)
QSPI_D0_B: U7.5 (DI(IO0)), U9.53 (QSPI_SD0)
QSPI_D1_B: U7.2 (DO(IO1)), U9.55 (QSPI_SD1)
QSPI_D2_B: U7.3 (IO2), U9.54 (QSPI_SD2)
QSPI_D3_B: U7.7 (IO3), U9.51 (QSPI_SD3)
QSPI_NCS_B: R9.2, R12.1, U7.1 (~CS), U9.56 (QSPI_SS)
RXB: U8.4 (I/O2), U9.2 (GPIO0)
SW22: SW22.1, U9.5 (GPIO3)
SW23: SW23.1, U9.6 (GPIO4)
SW24: SW24.1, U9.7 (GPIO5)
SW25: SW25.1, U9.8 (GPIO6)
SW26: SW26.1, U9.9 (GPIO7)
SW27: SW27.1, U9.11 (GPIO8)
SW28: SW28.1, U9.12 (GPIO9)
SW29: SW29.1, U9.13 (GPIO10)
SW30: SW30.1, U9.14 (GPIO11)
SW31: SW31.1, U9.15 (GPIO12)
SW32: SW32.1, U9.16 (GPIO13)
SW33: SW33.1, U9.17 (GPIO14)
SW34: SW34.1, U9.27 (GPIO16)
SW35: SW35.1, U9.28 (GPIO17)
SW36: SW36.1, U9.29 (GPIO18)
SW37: SW37.1, U9.30 (GPIO19)
SW38: SW38.1, U9.31 (GPIO20)
SW39: SW39.1, U9.32 (GPIO21)
SW40: SW40.1, U9.36 (GPIO24)
SW41: SW41.1, U9.35 (GPIO23)
SW42: SW42.1, U9.34 (GPIO22)
TXB: U8.6 (I/O1), U9.3 (GPIO1)
XINB: C55.1, U9.20 (XIN), Y2.3
XOUTB: R15.1, U9.21 (XOUT)

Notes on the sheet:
Capacitors should have C0G dialectric to minimize DC bias.
1k resistor to not overdrive the crystal
Level shifting
NOR FLASH
MCU and decoupling
USB C Split Connection and ESD
Switch matrix
QUARTZ CRYSTAL
LEDs and decoupling capacitors
USB C Power and ESD
MAKE SURE TO SWAP THE TXB AND RXB PIN ON THE OTHER BOARD

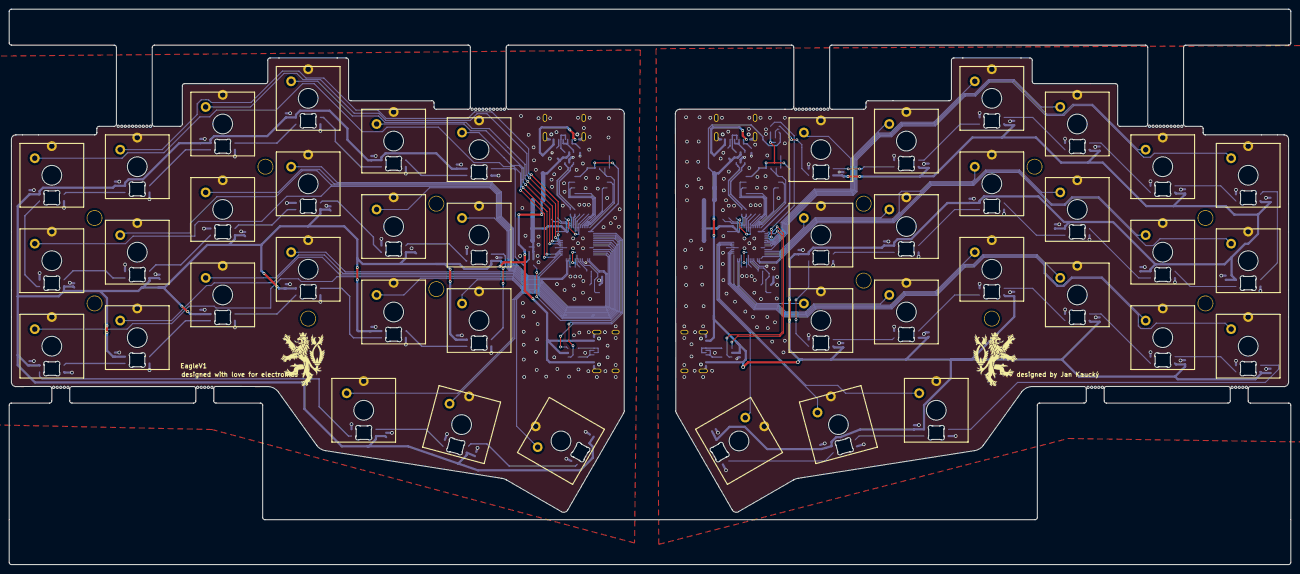
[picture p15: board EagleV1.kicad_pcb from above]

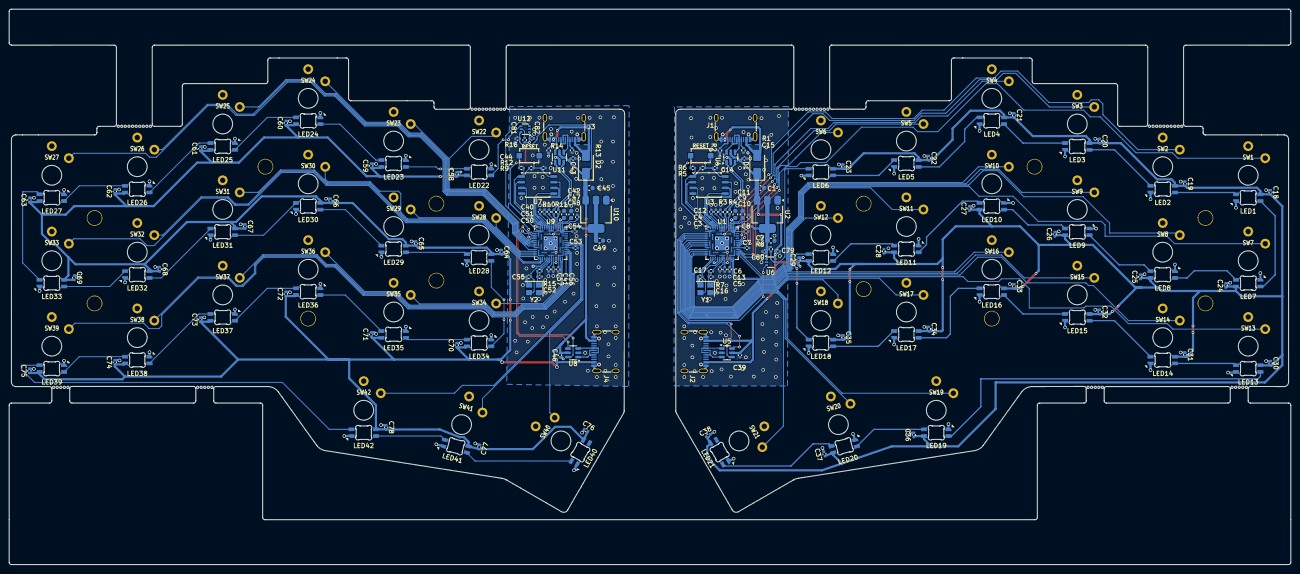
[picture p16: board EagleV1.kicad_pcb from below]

Board: 2 copper layers, 285.7 x 123.8 mm, 216 parts (162 on the bottom side), 142 nets.

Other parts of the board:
Mousbites 0.5mm NPTH with 0.3mm spacing, Mousbites 0.5mm NPTH with 0.3mm spacing#2, Mousbites 0.5mm NPTH with 0.3mm spacing#3, Mousbites 0.5mm NPTH with 0.3mm spacing#4, Mousbites 0.5mm NPTH with 0.3mm spacing#5, Mousbites 0.5mm NPTH with 0.3mm spacing#6, Mousbites 0.5mm NPTH with 0.3mm spacing#7, Mousbites 0.5mm NPTH with 0.3mm spacing#8, Mousbites 0.5mm NPTH with 0.3mm spacing#9, Mousbites 0.5mm NPTH with 0.3mm spacing#10, Mousbites 0.5mm NPTH with 0.3mm spacing#11, Mousbites 0.5mm NPTH with 0.3mm spacing#12: Corne_mousebites

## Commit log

2025-02-02 created a repo
    [Eagle_v1_Plate v3.stl, plate-2025-02-01T21_11_14.486Z.dxf]
2025-02-02 added a v2 plate
    [plate-2025-02-02T12_07_12.968Z.dxf]
2025-02-02 created a 3d model for v2 plate
    [EagleV1_PlateV2.stl]
2025-02-02 created a kicad project
    [EagleV1.kicad_pcb, EagleV1.kicad_sch]
2025-02-04 creating a schematic
    [EagleV1.kicad_sch, LeftSide.kicad_sch, RightSide.kicad_sch]
2025-02-10 finished schematic
    [EagleV1.kicad_pcb, LeftSide.kicad_sch, PlateV3.f3d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]
2025-02-13 started keyboard rounting
    [EagleV1 v12.stl, EagleV1.kicad_pcb, LeftSide.kicad_sch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]
2025-02-15 finished pcb layout
    [LeftSide.kicad_sch, RightSide.kicad_sch]
2025-02-16 routed all the tracks and smds
    [EagleV1.kicad_pcb, RightSide.kicad_sch]
2025-02-16 Finished layout, both halves
    [EagleV1.kicad_pcb, RightSide.kicad_sch]
2025-02-19 finished the PCB layout, exported gerbers
    [EagleV1.kicad_pcb, bom.csv, designators.csv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]
2025-02-20 edited LED caps via placement and added some finishing touches
    [EagleV1.kicad_pcb, designators.csv, positions.csv]
2025-02-25 V1 now finalized, meaby will play a little with the silkscreen
